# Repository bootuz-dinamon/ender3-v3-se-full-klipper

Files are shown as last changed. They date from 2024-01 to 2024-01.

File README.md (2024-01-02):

# ender3-v3-se-full-klipper

Klipper config for Creality Ender-3 V3 SE with driver section.

For CR4NS200320C13_32_MS35774_GD303RET6 mainboard (M4 label).
https://s.click.aliexpress.com/e/_Dmdyedv

With current control for stepper motors.
Now the motors do not overheat.

This is a complete configuration, it is enough for Klipper to work fully.

There is also a compiled file klipperXX_xxxxxxxxx.bin  v0.12.0-303, but I recommend compiling this file yourself.

klipper12_type_c.bin   - for connection via type-c connector (USART1 PA10/PA9).

klipper12_LCD_connector.bin  - for connection via IDC 10 pin LCD connector (USART3 PB11/PB10).

After installation you need to do:
1. Bed mesh calibrate
2. Manual calibrate Z-offset
3. Calibrate bed and extruder PID.

https://youtu.be/LrBiwabN-Y8

IMAGE ALT TEXT (http://www.youtube.com/watch?v=LrBiwabN-Y8 "Creality Ender3 V3 SE Klipper")

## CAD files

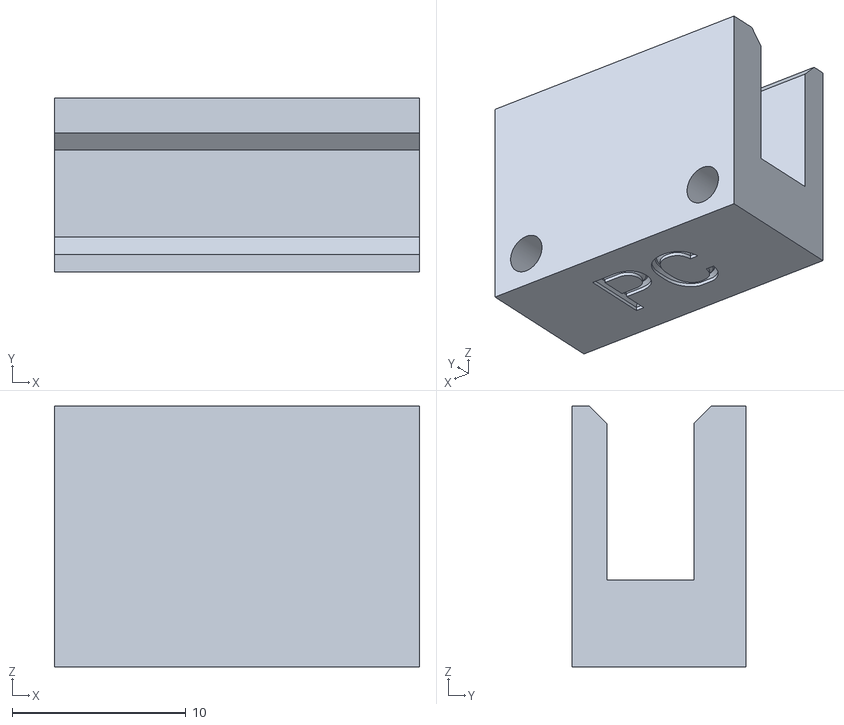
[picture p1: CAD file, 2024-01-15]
Config from Nebula pad/Ender_3_V3_SE_ADXL345_PC_Adapter.stl
21.0 x 10.0 x 15.0

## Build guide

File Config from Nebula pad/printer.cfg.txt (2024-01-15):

# !Ender-3 V3 SE:1:GD32F303 CR4NS200320C13
# printer_size: 220x220x250
# version: v1.2.0
# CreateDate: 2023/07/27
# mcu: chip: GD32F303RET6
#      version: CR4NS200323C13

[include timelapse.cfg]

[include sensorless.cfg]

[include gcode_macro.cfg]

[include printer_params.cfg]

[mcu]
serial:/dev/ttyS1
baud:230400
restart_method: command

[force_move]
enable_force_move: True

[mcu rpi]
serial: /tmp/klipper_host_mcu

[adxl345]
cs_pin: rpi:None
spi_speed: 2000000
spi_bus: spidev2.0

[resonance_tester]
accel_chip: adxl345
accel_per_hz: 70
probe_points:
    117.5,117.5,10

[bl24c16f]
i2c_mcu: rpi
i2c_bus: i2c.2
i2c_speed: 400000

######################################################
[prtouch_v2]
pres_cnt: 1                     #探点次数
pres0_clk_pins: PA4             #压力检测时钟引脚配置
pres0_sdo_pins: PC6             #压力检测数据引脚配置
step_swap_pin: PA15
pres_swap_pin: PA15
step_base:2
# show_msg: True
tri_min_hold: 1000
tri_max_hold: 1500            #压力检测信息展示
speed: 1
# tri_wave_ip: 172.22.30.204
#####################################################

[z_compensate]
tri_min_hold: 1400
tri_max_hold: 2000            #压力检测信息展示
tri_expand_mm = 0.07
# tri_min_hold: 3
speed: 5
hot_start_temp: 180#擦喷嘴是最小温度
hot_rub_temp: 200#擦喷嘴是最小温度
hot_end_temp: 140#擦喷嘴是最小温度
bed_add_temp: 60#调平时的热床温度
clr_noz_start_x: 0 #擦喷头区域的起始x坐标（默认在热床后方正中心位置）
clr_noz_start_y: 5 #擦喷头区域的起始y坐标
clr_noz_len_x: 3 #擦喷头区域的x方向的长度
clr_noz_len_y: 50 #擦喷头区域的y方向的长度
pa_clr_dis_mm_x = 0
pa_clr_dis_mm_y =30
# show_msg = True
bl_offset:-24,-20
noz_pos_center: 20,25
noz_pos_offset: 3,7
pumpback_mm: 10
vs_start_z_pos: 3
pr_probe_cnt: 3
pr_clear_probe_cnt: 3
type_nozz = 0

[printer]
kinematics: cartesian
max_velocity: 300
max_accel: 3000
max_accel_to_decel: 3000
max_z_velocity: 100
square_corner_velocity: 5.0
max_z_accel: 500

[idle_timeout]
timeout: 99999999

[stepper_x]
step_pin: PC2
dir_pin: !PB9
enable_pin: !PC3
microsteps: 16
rotation_distance: 40
endstop_pin: !PA5
position_endstop: -11
position_min: -15
position_max: 220
homing_speed: 40
homing_retract_dist:0 #10

[tmc2208 stepper_x]
uart_pin:PB12
interpolate: True
run_current:0.6
sense_resistor: 0.150
stealthchop_threshold: 0

[stepper_y]
step_pin: PB8
dir_pin: PB7
enable_pin: !PC3
microsteps: 16
rotation_distance: 40
endstop_pin: !PA6
position_endstop: -20
position_min: -20
position_max: 220
homing_speed: 40
homing_retract_dist:0

[tmc2208 stepper_y]
uart_pin:PB13
interpolate: True
run_current:0.6
sense_resistor: 0.150
stealthchop_threshold: 0

[stepper_z]
step_pin: PB6
dir_pin: !PB5
enable_pin: !PC3
microsteps: 16
rotation_distance:8
endstop_pin:probe:z_virtual_endstop#PA15   #probe:z_virtual_endstop
position_max: 250
position_min: -5

[tmc2208 stepper_z]
uart_pin: PB14
interpolate: True
run_current: 0.6
stealthchop_threshold: 0
sense_resistor: 0.150

[bltouch]
sensor_pin:PC14
control_pin: PC13
x_offset: -24
y_offset: -20
#z_offset: 0
probe_with_touch_mode: true
stow_on_each_sample: false
speed:5
lift_speed:20
# samples:3
# samples_result: median#median #average

#[safe_z_home]
#home_xy_position:134,130
#speed: 200
#z_hop: 10
#z_hop_speed: 5

[filament_switch_sensor filament_sensor]
switch_pin: !PC15
pause_on_runout: true

[output_pin MainBoardFan]
pin: !PB1

[extruder]
max_extrude_only_distance:1000
max_extrude_cross_section:80
pressure_advance = 0.04
step_pin: PB4
dir_pin: PB3
enable_pin: !PC3
microsteps: 16
rotation_distance: 7.53
nozzle_diameter: 0.400
filament_diameter: 1.750
heater_pin: PA1
sensor_type: EPCOS 100K B57560G104F
sensor_pin: PC5
#control = pid
#pid_Kp=20.584
#pid_Ki=1.737
#pid_Kd=60.981
min_temp: 0
max_temp: 320 # Set to 300 for S1 Pro

[heater_bed]
heater_pin: PB2
sensor_type: EPCOS 100K B57560G104F
sensor_pin: PC4
#control = pid
#pid_kp = 70.652
#pid_ki = 1.798
#pid_kd = 694.157
min_temp: 0
max_temp: 130
# temp_offset_flag = True

[verify_heater extruder]

[verify_heater heater_bed]
check_gain_time: 120
heating_gain: 1.0
hysteresis: 10

[temperature_sensor mcu_temp]
sensor_type: temperature_mcu
min_temp: 0
max_temp: 100

[output_pin fan0]
pin:PA0
pwm: True
cycle_time: 0.0100
hardware_pwm: false
value: 0.00
scale: 255
shutdown_value: 0.0

[heater_fan nozzle_fan]
pin: PC1
max_power: 1.0
shutdown_speed: 0
cycle_time: 0.010
hardware_pwm: False
kick_start_time: 0.100
off_below: 0.0
heater: extruder
fan_speed: 1.0
heater_temp: 60.0

[bed_mesh]
speed: 350
mesh_min: 5,10        #need to handle head distance with bl_touch
mesh_max: 190,200       #max probe range
probe_count: 5,5
fade_start: 1
fade_end: 10
fade_target: 0
horizontal_move_z: 8

[input_shaper]
#shaper_type_y = mzv
#shaper_freq_y = 35.0

#*# <---------------------- SAVE_CONFIG ---------------------->
#*# DO NOT EDIT THIS BLOCK OR BELOW. The contents are auto-generated.
#*#
#*# [bltouch]
#*# z_offset = 1.494
#*#
#*# [extruder]
#*# control = pid
#*# pid_kp = 29.970
#*# pid_ki = 1.586
#*# pid_kd = 141.608
#*#
#*# [heater_bed]
#*# control = pid
#*# pid_kp = 64.798
#*# pid_ki = 0.678
#*# pid_kd = 1547.865
#*#
#*# [bed_mesh default]
#*# version = 1
#*# points =
#*# 	0.192500, 0.040000, -0.002500, -0.015000, 0.047500
#*# 	0.075000, 0.010000, -0.002500, -0.005000, 0.037500
#*# 	0.047500, 0.042500, -0.010000, -0.012500, 0.030000
#*# 	0.042500, 0.022500, 0.007500, -0.007500, 0.062500
#*# 	0.092500, 0.047500, 0.037500, 0.065000, 0.102500
#*# x_count = 5
#*# y_count = 5
#*# mesh_x_pps = 2
#*# mesh_y_pps = 2
#*# algo = lagrange
#*# tension = 0.2
#*# min_x = 5.0
#*# max_x = 190.0
#*# min_y = 10.0
#*# max_y = 200.0
#*#
#*# [input_shaper]
#*# shaper_type_x = mzv
#*# shaper_freq_x = 44.0
#*# shaper_type_y = mzv
#*# shaper_freq_y = 33.2

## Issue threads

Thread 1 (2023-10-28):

Pressure Advance Mistake

arismelachroinos, 2023-10-28:
I believe you made a mistake on the pressure advance value.
I think you multiplied the mm with 0.02 instead of 0.005.
Instead of 0.17, I think the correct value is somewhere around 0.065..

arismelachroinos, 2023-10-28:
anyhow, thanks for your tutorial video & config files, they helped me a lot.

bootuz-dinamon, 2023-10-28:
I will be grateful if you saddle up your test on Pressure Advance and publish your data. I recalculated my cube and it came out to about 0.135.

arismelachroinos, 2023-10-28:
Here is my result:
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
I am measuring 11.24mm from the bottom of the print, where I believe the corners are of the best quality. I am multiplying 11.24*0.005 = 0.0562

arismelachroinos, 2023-10-28:
Please let me know if I am doing something wrong.

bootuz-dinamon, 2023-11-05:
pressure_advance: 0.04

arismelachroinos, 2023-11-05:
This seems a lot more reasonable

arismelachroinos, 2023-11-05:
This seems a lot more reasonable

Closed 2023-11-05.

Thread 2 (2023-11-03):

Extruder not hot enough?

pwlgrzs, 2023-11-03:
Hello,
thank you for creating this and the guide on YouTube. Quick question, I have added "PRINT_START" as Start G-Code in PrusaSlicer (actually didn't notice I have not ;) ) and now when printing starts it's getting cancelled with:
```
16:07:38  File opened:3DBenchy_46m_0.20mm_230C_PET_.gcode Size:3292043
16:07:38  File selected
16:09:18  // Extrude below minimum temp
// See the 'min_extrude_temp' config option for details
16:09:18  !! Extrude below minimum temp
```

bootuz-dinamon, 2023-11-03:
When using a macro to start printing, you need to specify the heating of the hotend and bed in the macro itself. I'll fix it a little later.

For now, I recommend writing not a macro, but a
 G-code.

michaeldemchenko, 2023-11-19:
I encountered a problem while using Orca Slicer with the given G-Code. It appeared that the current G-Code was only compatible with Cura. To make it work with Orca Slicer, I had to use some settings from my previous print and combine them with a few lines of code from the given G-Code.

```shell
G90 ; use absolute coordinates
M83 ; extruder relative mode

M104 S150 ; set temporary nozzle temp to prevent oozing during homing
M140 S[bed_temperature_initial_layer_single] ; set final bed temp
G4 S30 ; allow partial nozzle warmup
G28 ; home all axis and restore leveling

G1 Z50 F240
G1 X2.0 Y10 F3000
M104 S[nozzle_temperature_initial_layer] ; set final nozzle temp
M190 S[bed_temperature_initial_layer_single] ; wait for bed temp to stabilize
M109 S[nozzle_temperature_initial_layer] ; wait for nozzle temp to stabilize

G1 Z0.28 F240
G92 E0; Reset Extruder

G1 X2.0 Y140 E10 F1500 ; prime the nozzle
G1 X2.3 Y140 F5000
G92 E0; Reset Extruder

G1 X2.3 Y10 E10 F1200 ; prime the nozzle
G92 E0; Reset Extruder

G1 Z2.0 F3000 ; Move Z Axis up little to prevent scratching of Heat Bed
G1 X5 Y20 Z0.3 F5000.0 ; Move over to prevent blob squish
BED_MESH_PROFILE LOAD=default
```

mshrem, 2023-11-21:
I just received the printer and spent the most part of the day figuring this out, i see that the commands for cura are updated in the gcode section.

However i am still getting a Unknown gcode_macro variable 'bed_temp' error

mshrem, 2023-11-28:
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

Do you happen to have a profile for orca slicer that i can use ?

KSEGIT, 2024-05-14:
I had similar problem and found what the issue was!

Installed plugins:
-ElegooNeptuneThumbnails
-Klipper settings
-Moonraker connection
-Settings guide

Even though I had configured my printer settings in Cura to use START_PRINT macro for klipper. Cura was not adding it to my gcode file. I fixed it by turning off all Post Processing Scripts in Extensions>Post Processing>Modify G-code. Now Prints are loading/starting fine in klipper.

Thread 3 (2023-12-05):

Klipper Ender 3 V3 KE

weismantelf, 2023-12-05:
Hello,
I saw your video on you tube about the Ender 3 V3 KE.
Great job!

How can I use full klipper version on Ender 3 V3 KE?

Would be nice, if you can help.

bootuz-dinamon, 2023-12-05:
To do this, you will need the correct printer.cfg (I think that very soon they will already be on the Internet), you will need a single-board computer like Orange pi Zero 3. And you can buy a USB-UART cable from Creality -https://s.click.aliexpress.com/e/_DlkYQB3

Closed 2023-12-06.

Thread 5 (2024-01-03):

Question about speed setting

felipejfc, 2024-01-03:
First of all, thanks for all the work you put into this config. Been trying with it and it seems to be working very well!

One question though, why is your speed setting so low?

```
[printer]
kinematics: cartesian
max_velocity: 150
max_accel: 3000
max_accel_to_decel: 3000
max_z_velocity: 50
square_corner_velocity: 5.0
max_z_accel: 500
```

Even in marlin I think this is set to 500, am I missing something?

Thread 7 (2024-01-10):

Klippy/extras ?

freeman5, 2024-01-10:
Hi,

what we have to do with this folder ? its need to put it before compile the klipper ? thank

bootuz-dinamon, 2024-01-10:
EXTRA folder don`t needed.

freeman5, 2024-01-10:
Yes but the extra folder include PRTOUCH_PROBE_ZOFFSET ?

freeman5, 2024-01-10:
Ok, i start by zero, i recompile correctly the firmware, with  # "Enable extra low-leverl configuration options" and "Disable SWD on startup" i add klippy/extras file, i add include prtouch.cfg in printer.cfg and i have this erreur : Option 'clr_noz_len_y' in section 'prtouch' must have minimum of 25

i have try the fork of 0xD34D, with the config file, and the PRTOUCH_PROBE_ZOFFSET work, but i prefer your config, because you use original fork with better macro, but im looking for auto zoffset too ^^

freeman5, 2024-01-10:
if i look this file : https://github.com/0xD34D/klipper_ender3_v3_se/blob/master/klippy/extras/prtouch.py
i have the wipe_retract_distance variable :/

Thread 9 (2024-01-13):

Unknown command:

eemersonrosa, 2024-01-13:
I am getting the following errors with the current config:

01:21:33 PM
// Unknown command:"M205"
01:21:38 PM
Done printing file
01:32:41 PM
// Unknown command:"POWER_OFF_PRINTER"
01:37:44 PM
File opened:CE3V3SE_block.gcode Size:26149553
01:37:44 PM
File selected

bootuz-dinamon, 2024-01-13:
You can comment out this command in the End g-code macro.
I use it to turn off the printer after printing and while the extruder is cooling. Described in the Moonraker documentation https://moonraker.readthedocs.io/en/latest/configuration/   in [power] section.

eemersonrosa, 2024-01-13:
What about the "M205"?

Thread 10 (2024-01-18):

No connection via UART

Yackushev, 2024-01-18:
Unable to connect the board via UART.
Host board - BTT Pi.
I flashed klipper12_LCD_connector.bin.
Then I checked contacts RX and TX from LCD connector.
These are PA2 and PA3, not PB11/PB10.
I compiled the firmware with these pins, but there is still no connection.
Has anyone managed to connect the board via UART?

Yackushev, 2024-10-18:
No, I still couldn't connect via UART.
I connected via USB.
I suspect that the UART-USB converter chip is to blame.
I wanted to unsolder it to check, then I thought it wasn't worth it.

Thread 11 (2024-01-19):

Klipper12 lcd connector. Is this to enable the stock screen?

SPYKE357, 2024-01-19:
Hi, not an issue as such but more of a question. Is there a way to enable the stock screen? Have everything else working great. Prtouch zoffset etc... Thank you by the way...

Yackushev, 2024-01-20:
No, this is for connecting via UART.
The screen is not working yet. There is a person on reddit who started working with the screen. Maybe he can do it.

Yackushev, 2024-01-20:
> Hi, not an issue as such but more of a question. Is there a way to enable the stock screen? Have everything else working great. Prtouch zoffset etc... Thank you by the way...

No, this is for connecting via UART.
The screen is not working yet. There is a person on reddit who started working with the screen. Maybe he can do it.

Shubham-Sus, 2024-04-07:
> > Hi, not an issue as such but more of a question. Is there a way to enable the stock screen? Have everything else working great. Prtouch zoffset etc... Thank you by the way...
>
> No, this is for connecting via UART. The screen is not working yet. There is a person on reddit who started working with the screen. Maybe he can do it.

Any Update on this ?

jpcurti, 2024-05-15:
If you have it running on a RPi (connected to the printer via USB) and can connect the display to the Pi directly, you can use this project to make the screen "work again": https://github.com/jpcurti/E3V3SE_display_klipper

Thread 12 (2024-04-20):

wled how to? not an issue just asking for help

SPYKE357, 2024-04-20:
good morning

i have this branch of klipper on my se and saw that there's a wled config, how is it controlled and wired up, would like to do the same to have a controllable caselight if possible.

your help will be greatly appreciated.

Furthermore, thank you very much for this build. been very happy with it since release.

bootuz-dinamon, 2024-04-21:
Information on how to connect and use wled can be found in the moonraker documentation.

SPYKE357, 2024-04-21:
> Information on how to connect and use wled can be found in the moonraker documentation.

Thank you, but how do you wire it up? the moonraker config seems easy enough but i have no idea how to wire the strip to the printer to enable control over moonraker.

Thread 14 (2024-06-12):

CR Touch probe driving into bed

notleks2411, 2024-06-12:
I am not sure if this is normal or not, but when I go to calibrate the bed mesh in Fluidd, the CR Touch probe hits the bed fairly harder than the stock V3 SE when probing, and when moving the Y-axis, it seems to try and want to push it further than it can.

Is this normal? I can record a video if it helps explain.

notleks2411, 2024-06-12:
https://youtu.be/2OAAK0HoNmM

LancerGM, 2024-06-27:
The probe seems to be moving at the correct speed. The Y axis does the same thing on mine, but this can be configured in your printer.cfg by adjusting the maximum movement distance on the Y axis. I believe it's not a problem and the noise is caused by the subpar linear rods and rollers, but I might be wrong on that.

davidkeeton, 2024-10-19:
Same issue, infact the probe is completely useless. almost 6mm out

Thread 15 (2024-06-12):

"Option 'max_accel_to_decel' in section 'printer' is deprecated."

notleks2411, 2024-06-12:
This message is appearing in Fluidd.

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

seregaass, 2024-07-10:
у меня так же, вы решили эту проблемму?

whc2001, 2024-10-12:
I am new to Klipper and don't really understand what this option does, and seems like it's being replaced by `minimum_cruise_ratio`. From [this post](https://klipper.discourse.group/t/proportional-acceleration-control/3970) seems like the `max_accel_to_decel` is related to `max_accel`, and since in the config it's both `3000`, according to [this formula](https://klipper.discourse.group/t/error-on-set-velocity-limit-accel-to-decel-unable-to-parse/15213/9), the function is essentially disabled and we can just write `minimum_cruise_ratio: 0` in place.

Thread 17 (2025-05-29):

prtouch.cfg

kacade22, 2025-05-29:
first thanks for your hard work but i have question regarding
prtouch.cfg
when i add in printer.cfg is not working and msg come out
do i need to do something or maybe am wrong ?
or it's old for new klipper
and i flash your firmware.bin that premake

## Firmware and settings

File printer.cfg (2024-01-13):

# This file contains pin mappings for the stock 2022 Creality Ender 3
# V3 SE. To use this config, during "make menuconfig" select the
# STM32F103 with a "28KiB bootloader" and serial (on USART1 PA10/PA9)
# communication.
# "Enable extra low-leverl configuration options" and "Disable SWD on startup"

# If you prefer a direct serial connection, in "make menuconfig"
# select "Enable extra low-level configuration options" and select
# serial (on USART3 PB11/PB10), which is broken out on the 10 pin IDC
# cable used for the LCD module as follows:
# 3: Tx, 4: Rx, 9: GND, 10: VCC

# Don`t forget "make"

# Flash this firmware by copying "out/klipper.bin" to a SD card and
# turning on the printer with the card inserted. The firmware
# filename must end in ".bin" and must not match the last filename
# that was flashed.

# cp out/klipper.bin /home/orangepi/printer_data/config/

# See docs/Config_Reference.md for a description of parameters.

[include fluidd.cfg]

[include macro.cfg]

[virtual_sdcard]
path: ~/printer_data/gcodes
on_error_gcode: CANCEL_PRINT

#[input_shaper]
#shaper_type_y = mzv
#shaper_freq_y = 35.0

[stepper_x]
step_pin: PC2
dir_pin: !PB9
enable_pin: !PC3
microsteps: 64
rotation_distance: 40
endstop_pin: !PA5
position_endstop: -6
position_min: -6
position_max: 230
homing_speed: 50

[stepper_y]
step_pin: PB8
dir_pin: PB7
enable_pin: !PC3
microsteps: 64
rotation_distance: 40
endstop_pin: !PA6
position_endstop: -14
position_min: -14
position_max: 230
homing_speed: 50

[stepper_z]
step_pin: PB6
dir_pin: !PB5
enable_pin: !PC3
microsteps: 16
rotation_distance: 8
endstop_pin: probe:z_virtual_endstop
position_min: -3
position_max: 250
homing_speed: 4
second_homing_speed: 1
homing_retract_dist: 2.0

[extruder]
max_extrude_only_distance: 100.0
pressure_advance: 0.04
step_pin: PB4
dir_pin: PB3
enable_pin: !PC3
microsteps: 16
rotation_distance: 7.44
nozzle_diameter: 0.400
filament_diameter: 1.750
heater_pin: PA1
sensor_type: EPCOS 100K B57560G104F
sensor_pin: PC5
control: pid
# tuned for stock hardware with 200 degree Celsius target
pid_Kp: 27.142
pid_Ki: 1.371
pid_Kd: 134.351
min_temp: 0
max_temp: 260

[heater_bed]
heater_pin: PB2
sensor_type: EPCOS 100K B57560G104F
sensor_pin: PC4
control: pid
# tuned for stock hardware with 70 degree Celsius target
pid_kp: 66.371
pid_ki: 0.846
pid_kd: 1301.702
min_temp: 0
max_temp: 100

[heater_fan hotend_fan]
pin: PC1
max_power: 1.0
shutdown_speed : 0
cycle_time: 0.010
hardware_pwm: false
kick_start_time: 0.100
off_below: 0.0
heater:extruder
heater_temp : 50
fan_speed : 1.0

[fan]
pin: PA0



[mcu]
serial: /dev/serial/by-id/usb-1a86_USB_Serial-if00-port0
#serial: /dev/ttyUSB0
restart_method: command

[printer]
kinematics: cartesian
max_velocity: 150
max_accel: 3000
max_accel_to_decel: 3000
max_z_velocity: 50
square_corner_velocity: 5.0
max_z_accel: 500

[bltouch]
sensor_pin: ^PC14
control_pin: PC13
x_offset: -24.0
y_offset: -13.0
z_offset: 0.1
speed: 20
pin_move_time: 0.4
stow_on_each_sample: False
probe_with_touch_mode: True

[safe_z_home]
home_xy_position: 134,123
speed: 50
z_hop: 10
z_hop_speed: 5

[bed_mesh]
speed: 120
horizontal_move_z: 5
mesh_min: 30,30         # Need to handle head distance with cr-touch (bl_touch)
mesh_max: 205,215.5       # Max probe range
probe_count: 5,5
algorithm: bicubic

# [display]
# NOT IMPLEMTED (assuming it even works)

[output_pin beeper]
pin: PB0


[tmc2209 stepper_x]
uart_pin: PB12
run_current: 0.60
sense_resistor: 0.150
stealthchop_threshold: 0
interpolate: false

[tmc2209 stepper_y]
uart_pin: PB13
run_current: 0.60
sense_resistor: 0.150
stealthchop_threshold: 0
interpolate: false

[tmc2209 stepper_z]
uart_pin: PB14
run_current: 0.8
sense_resistor: 0.150
stealthchop_threshold: 0
interpolate: false

[temperature_sensor mcu_temp]
sensor_type: temperature_mcu
min_temp: 0
max_temp: 100

[temperature_sensor Orange_Pi]
sensor_type: temperature_host
min_temp: 10
max_temp: 100

[pause_resume]
recover_velocity: 25

[display_status]

[respond]

[delayed_gcode DELAYED_PRINTER_OFF]
initial_duration = 0.
gcode =
  {% if printer.idle_timeout.state == "Idle" %}
    {% if printer["extruder"].temperature > 50 %}
      UPDATE_DELAYED_GCODE ID=DELAYED_PRINTER_OFF DURATION=60
    {% else %}
#      WLED_OFF STRIP=roof
      POWER_OFF_PRINTER
    {% endif %}
  {% else %}
    M118 Printer not idle, cancelled PRINTER_OFF.
  {% endif %}

[idle_timeout]
gcode:
  M84
  TURN_OFF_HEATERS
  UPDATE_DELAYED_GCODE ID=DELAYED_PRINTER_OFF DURATION=60

#*# <---------------------- SAVE_CONFIG ---------------------->
#*# DO NOT EDIT THIS BLOCK OR BELOW. The contents are auto-generated.
#*#

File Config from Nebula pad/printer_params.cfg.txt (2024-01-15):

[custom_macro]
default_bed_temp: 60
default_extruder_temp: 220
g28_ext_temp: 140
temp_diff: 40
calibration_zoffset_flags:0

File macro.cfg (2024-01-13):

[gcode_macro PID_EXTRUDER]
gcode:
  PID_CALIBRATE HEATER=extruder TARGET=210
  SAVE_CONFIG

[gcode_macro PID_BED]
gcode:
  PID_CALIBRATE HEATER=heater_bed TARGET=60
  SAVE_CONFIG

#Cura start g-code
# START_PRINT EXTRUDER_TEMP={material_print_temperature_layer_0} BED_TEMP={material_bed_temperature_layer_0}

# All start end g-codes:
# https://github.com/rootiest/zippy_guides/blob/main/guides/macros.md#slicer-settings


[gcode_macro START_PRINT]          # START_PRINT 
gcode:
    {% set BED_TEMP = params.BED_TEMP|default(60)|float %}
    {% set EXTRUDER_TEMP = params.EXTRUDER_TEMP|default(190)|float %}
    M140 S{BED_TEMP}
#    WLED_ON STRIP=roof PRESET=6
    ; Ender 3 Custom Start G-code
    G92 E0 ; Reset Extruder
    G28 ; Home all axes
        # Wait for bed to reach temperature
    M190 S{BED_TEMP}
    # Set and wait for nozzle to reach temperature
    M109 S{EXTRUDER_TEMP}
    G1 Z2.0 F3000 ; Move Z Axis up little to prevent scratching of Heat Bed
    G1 X0.1 Y20 Z0.3 F5000.0 ; Move to start position
    G1 X0.1 Y200.0 Z0.3 F1500.0 E15 ; Draw the first line
    G1 X0.4 Y200.0 Z0.3 F5000.0 ; Move to side a little
    G1 X0.4 Y20 Z0.3 F1500.0 E30 ; Draw the second line
    G92 E0 ; Reset Extruder
    G1 Z2.0 F3000 ; Move Z Axis up little to prevent scratching of Heat Bed
    G1 X5 Y20 Z0.3 F5000.0 ; Move over to prevent blob squish
    BED_MESH_PROFILE LOAD=default

[gcode_macro FILAMENT_LOAD]
gcode:
    {% set load = params.L|default(100)|float * 0.5 %}
    {% set extruder_temp = params.T|default(210)|float %}
    SAVE_GCODE_STATE NAME=FILAMENT_LOAD_STATE
    LOW_TEMP_CHECK T={extruder_temp}
    M118 Loading filament
    M83                                                                         # relative extrusion
    G1 E{load} F1500                                                            # extrude fast
    G4 P1000                                                                    # wait 1 second
    G1 E{load} F200                                                             # extrude slow
    RESTORE_GCODE_STATE NAME=FILAMENT_LOAD_STATE
    BEEP


[gcode_macro FILAMENT_UNLOAD]
gcode:
    {% set unload = params.U|default(100)|float %}
    {% set extruder_temp = params.T|default(200)|float %}
    SAVE_GCODE_STATE NAME=FILAMENT_UNLOAD_STATE
    LOW_TEMP_CHECK T={extruder_temp}
    M118 Unloading filament
    M83                                                                         # relative extrusion
    G1 E2  F200                                                                 # extrude a little
    G1 E-10  F200                                                               # retract a little
    G1 E-{unload} F1500                                                         # retract a lot
    RESTORE_GCODE_STATE NAME=FILAMENT_UNLOAD_STATE

[gcode_macro LOW_TEMP_CHECK]
gcode:
    {% set extruder_temp = params.T|default(200)|float %}
    {% if printer.extruder.target > extruder_temp %}                            # if there is a setpoint for extruder
        {% set extruder_temp = printer.extruder.target %}
    {% endif %}
    {% if printer.extruder.temperature < extruder_temp %}                       # heat to the target
        M118 Heating to {extruder_temp}
        SET_HEATER_TEMPERATURE HEATER=extruder TARGET={extruder_temp}
        TEMPERATURE_WAIT SENSOR=extruder MINIMUM={extruder_temp}
    {% endif %}

[gcode_macro BEEP]
gcode:
    {% set duration = params.P|default(100)|float %}
    SET_PIN PIN=beeper VALUE=1
    G4 P{duration}
    SET_PIN PIN=beeper VALUE=0


[gcode_macro CANCEL_PRINT]
description: Cancel the actual running print
rename_existing: CANCEL_PRINT_BASE
gcode:
  ##### get user parameters or use default #####
  {% set client = printer['gcode_macro _CLIENT_VARIABLE'] | default({}) %}
  {% set allow_park = client.park_at_cancel | default(false) | lower == 'true' %}
  {% set retract = client.cancel_retract | default(5.0) | abs %}
  ##### define park position #####
  {% set park_x = "" if (client.park_at_cancel_x | default(none) is none)
            else "X=" ~ client.park_at_cancel_x %}
  {% set park_y = "" if (client.park_at_cancel_y | default(none) is none)
            else "Y=" ~ client.park_at_cancel_y %}
  {% set custom_park = park_x | length > 0 or park_y | length > 0 %}
  ##### end of definitions #####
  # restore idle_timeout time if needed
  {% if printer['gcode_macro PAUSE'].restore_idle_timeout > 0 %}
    SET_IDLE_TIMEOUT TIMEOUT={printer['gcode_macro PAUSE'].restore_idle_timeout}
  {% endif %}
  {% if (custom_park or not printer.pause_resume.is_paused) and allow_park %} _TOOLHEAD_PARK_PAUSE_CANCEL {park_x} {park_y} {% endif %}
  _CLIENT_RETRACT LENGTH={retract}
  TURN_OFF_HEATERS
  M106 S0
  # clear pause_next_layer and pause_at_layer as preparation for next print
  SET_PAUSE_NEXT_LAYER ENABLE=0
  SET_PAUSE_AT_LAYER ENABLE=0 LAYER=0
  CANCEL_PRINT_BASE

[gcode_macro PAUSE]
description: Pause the actual running print
rename_existing: PAUSE_BASE
variable_restore_idle_timeout: 0
gcode:
  ##### get user parameters or use default #####
  {% set client = printer['gcode_macro _CLIENT_VARIABLE'] | default({}) %}
  {% set idle_timeout = client.idle_timeout | default(0) %}
  {% set temp = printer[printer.toolhead.extruder].target if printer.toolhead.extruder != '' else 0 %}
  {% set restore = printer.toolhead.extruder != '' and params.RESTORE | default(1) | int == 1 %}
  ##### end of definitions #####
  SET_GCODE_VARIABLE MACRO=RESUME VARIABLE=last_extruder_temp VALUE="{{'restore': restore, 'temp': temp}}"
  # set a new idle_timeout value
  {% if idle_timeout > 0 %}
    SET_GCODE_VARIABLE MACRO=PAUSE VARIABLE=restore_idle_timeout VALUE={printer.configfile.settings.idle_timeout.timeout}
    SET_IDLE_TIMEOUT TIMEOUT={idle_timeout}
  {% endif %}
  PAUSE_BASE
  _TOOLHEAD_PARK_PAUSE_CANCEL {rawparams}

[gcode_macro RESUME]
description: Resume the actual running print
rename_existing: RESUME_BASE
variable_last_extruder_temp: {'restore': False, 'temp': 0}
gcode:
  ##### get user parameters or use default #####
  {% set client = printer['gcode_macro _CLIENT_VARIABLE'] | default({}) %}
  {% set velocity = printer.configfile.settings.pause_resume.recover_velocity %}
  {% set sp_move = client.speed_move | default(velocity) %}
  ##### end of definitions #####
  # restore idle_timeout time if needed
  {% if printer['gcode_macro PAUSE'].restore_idle_timeout > 0 %}
    SET_IDLE_TIMEOUT TIMEOUT={printer['gcode_macro PAUSE'].restore_idle_timeout}
  {% endif %}
  {% if printer.idle_timeout.state | upper == "IDLE" and last_extruder_temp.restore %}
    M109 S{last_extruder_temp.temp}
  {% endif %}
  _CLIENT_EXTRUDE
  RESUME_BASE VELOCITY={params.VELOCITY | default(sp_move)}

# Usage: SET_PAUSE_NEXT_LAYER [ENABLE=[0 | 1]] [MACRO=<name>]
[gcode_macro SET_PAUSE_NEXT_LAYER]
description: Enable a pause if the next layer is reached
gcode:
  {% set pause_next_layer = printer['gcode_macro SET_PRINT_STATS_INFO'].pause_next_layer %}
  {% set ENABLE = params.ENABLE | default(1) | int != 0 %}
  {% set MACRO = params.MACRO | default(pause_next_layer.call, True) %}
  SET_GCODE_VARIABLE MACRO=SET_PRINT_STATS_INFO VARIABLE=pause_next_layer VALUE="{{ 'enable': ENABLE, 'call': MACRO }}"

# Usage: SET_PAUSE_AT_LAYER [ENABLE=[0 | 1]] [LAYER=<number>] [MACRO=<name>]
[gcode_macro SET_PAUSE_AT_LAYER]
description: Enable/disable a pause if a given layer number is reached
gcode:
  {% set pause_at_layer = printer['gcode_macro SET_PRINT_STATS_INFO'].pause_at_layer %}
  {% set ENABLE = params.ENABLE | int != 0 if params.ENABLE is defined
             else params.LAYER is defined %}
  {% set LAYER = params.LAYER | default(pause_at_layer.layer) | int %}
  {% set MACRO = params.MACRO | default(pause_at_layer.call, True) %}
  SET_GCODE_VARIABLE MACRO=SET_PRINT_STATS_INFO VARIABLE=pause_at_layer VALUE="{{ 'enable': ENABLE, 'layer': LAYER, 'call': MACRO }}"

# Usage: SET_PRINT_STATS_INFO [TOTAL_LAYER=<total_layer_count>] [CURRENT_LAYER= <current_layer>]
[gcode_macro SET_PRINT_STATS_INFO]
rename_existing: SET_PRINT_STATS_INFO_BASE
description: Overwrite, to get pause_next_layer and pause_at_layer feature
variable_pause_next_layer: { 'enable': False, 'call': "PAUSE" }
variable_pause_at_layer  : { 'enable': False, 'layer': 0, 'call': "PAUSE" }
gcode:
  {% if pause_next_layer.enable %}
    RESPOND TYPE=echo MSG='{"%s, forced by pause_next_layer" % pause_next_layer.call}'
    {pause_next_layer.call} ; execute the given gcode to pause, should be either M600 or PAUSE
    SET_PAUSE_NEXT_LAYER ENABLE=0
  {% elif pause_at_layer.enable and params.CURRENT_LAYER is defined and params.CURRENT_LAYER | int == pause_at_layer.layer %}
    RESPOND TYPE=echo MSG='{"%s, forced by pause_at_layer [%d]" % (pause_at_layer.call, pause_at_layer.layer)}'
    {pause_at_layer.call} ; execute the given gcode to pause, should be either M600 or PAUSE
    SET_PAUSE_AT_LAYER ENABLE=0
  {% endif %}
  SET_PRINT_STATS_INFO_BASE {rawparams}
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

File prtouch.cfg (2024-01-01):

[filter]

[dirzctl]

[hx711s]
sensor0_clk_pin: PA4             # Pressure detection clock pin
sensor0_sdo_pin: PC6             # Pressure detection data pin

[prtouch]
sensor_x: 32
sensor_y: 30
clr_noz_start_x: 15
clr_noz_start_y: 25
clr_noz_len_y: 15
s_hot_min_temp: 160
s_hot_max_temp: 200
s_bed_max_temp: 60
show_msg: True
wipe_retract_distance: 2

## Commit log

2023-10-24 Update macro.cfg
    Add macros PRINT_END
    [macro.cfg]
2023-11-04 Add input shaping
    [printer.cfg]
2023-11-05 Update printer.cfg
    pressure_advance: 0.04
    [printer.cfg]
2024-01-01 Add files via upload
    prtouch.cfg from https://github.com/0xD34D/ender3-v3-se-klipper-config
    [prtouch.cfg]
2024-01-02 Update to klipper 0.12
2024-01-03 add Power OFF if delayed
    Need Smart Plug and Home Assistant
    [macro.cfg, printer.cfg]
2024-01-06 Macros for wled
    [wled.cfg]
2024-01-15 Added config from Nebula pad
    [Ender_3_V3_SE_ADXL345_PC_Adapter.stl, printer_params.cfg.txt]
2024-01-24 Config for Fly ADXL345 usb
    [adxl.cfg]
